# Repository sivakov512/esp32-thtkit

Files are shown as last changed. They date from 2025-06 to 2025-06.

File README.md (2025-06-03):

# ESP32 THT Development Kits
**Ultra-Compact Through-Hole Development Boards for ESP32**



This repository contains design files and documentation for ultra-compact, through-hole (THT) friendly development boards based on Espressif ESP32 microcontrollers. These boards are designed for easy integration into breadboard and other through-hole prototyping environments.

## Available Development Kits

| DevKit | Description | SoC | Features |
|---|---|-----|---|
| [ESP32-C3-THTKIT](esp32-c3-thtkit/) | Ultra-compact ESP32-C3 development board with THT headers | ESP32-C3FH4 | WiFi, Bluetooth 5 (LE), RISC-V single-core |
| [ESP32-H2-THTKIT](esp32-h2-thtkit/) | Ultra-compact ESP32-H2 development board with THT headers | ESP32-H2FH4 | 802.15.4 (Thread, Zigbee), Bluetooth 5 (LE), RISC-V single-core |

## Key Features

- **Ultra-compact form factor**: Minimal dimensions for tight integration
- **Breadboard friendly**: Design optimized for breadboard prototyping
- **THT headers**: Standard 2.54mm pitch through-hole pins
- **Smart header layout**: Bottom header deliberately offset by 1.27mm (half pitch) to prevent accidental shorts in breadboards
- **Simple power supply**: 3.3V to 12V input with onboard LDO
- **Essential pins exposed**: Focused on providing the most important functionality
- **UART debug access**: Dedicated UART pins for easy programming and debugging
- **KiCad design files**: Complete open-source hardware design

## Design Philosophy

These development kits are designed with several principles in mind:
- **Minimal but complete**: Only essential components while maintaining full functionality
- **Direct integration**: Design that works in final projects, not just for prototyping
- **Hackable**: Easy to modify and adapt to specific needs
- **Open design**: Full schematics and PCB files available

## Getting Started

Visit each development kit's directory for specific documentation:

- [ESP32-C3-THTKIT Documentation](esp32-c3-thtkit/)
- [ESP32-H2-THTKIT Documentation](esp32-h2-thtkit/)

## License

This project is released under the [MIT License](LICENSE).

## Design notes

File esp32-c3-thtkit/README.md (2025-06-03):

# ESP32-C3-THTKIT
**Ultra-Compact THT-Friendly DevKit**



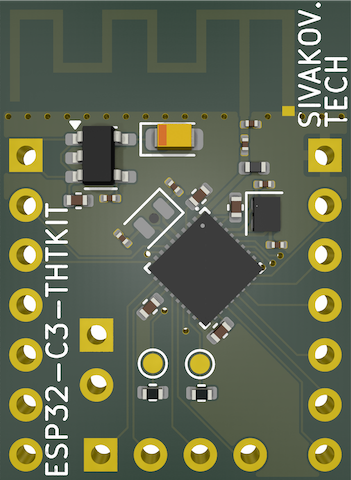
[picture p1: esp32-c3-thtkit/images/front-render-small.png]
Front render


---

## Overview

ESP32-C3-THTKIT is an ultra-compact development board based on the ESP32-C3FH4 SoC. Designed for direct THT integration, it exposes only essential functionality in a minimal form factor. UART pins are easily accessible at the top for in-circuit development.

---

## Pinout

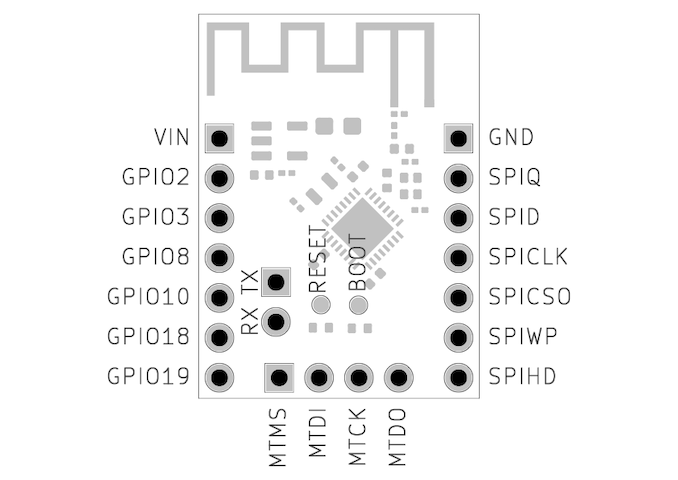
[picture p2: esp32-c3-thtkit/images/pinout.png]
Pinout


- Left header (THT): VIN, GPIO2 to GPIO19
- Right header (THT): GND, GPIO17 to GPIO12 (FSPI2 by default)
- Bottom header (THT): GPIO4 to GPIO7 (JTAG by default)
- Top edge: UART TX/RX pins
- BOOT/RESET: pad-based activation (short to GND)
- Pin pitch: 2.54 mm standard
- Bottom header deliberately offset by 1.27 mm (half pitch) to prevent accidental shorts when inserted into a breadboard

---

## Programming & Debugging

- UART programming recommended via top pins
- JTAG available on bottom header (default mapping)
- No USB functionality

---

## Electrical

- Input Voltage: 3.3V to 12V
- On-board LDO stabilizes to 3.3V
- No onboard USB

---

## Mechanical

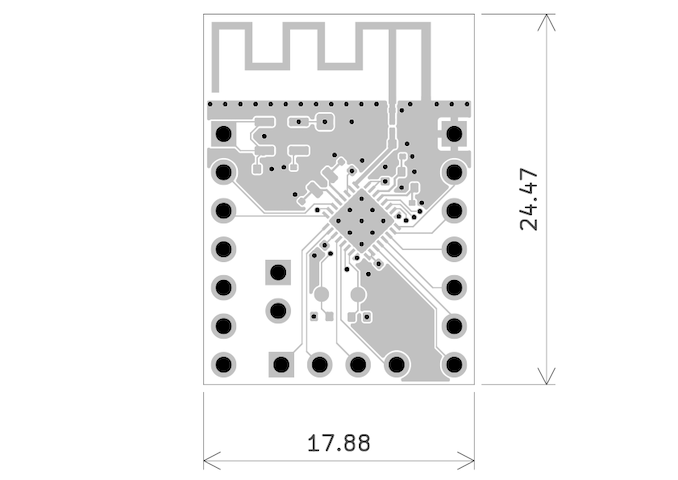
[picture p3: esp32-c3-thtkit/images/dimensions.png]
Dimensions


- Dimensions: 24.47 mm x 17.88 mm
- 3x THT headers: left, right, and optional bottom (user-soldered)

---

## Datasheet

[📄 ESP32-H2-THTKIT Datasheet (PDF)](docs/Datasheet.pdf)

[📄 ESP32-H2 Datasheet (Espressif)](https://cdn.jsdelivr.net/gh/sivakov512/kicad-library@master/datasheets/MCU/Espressif/Espressif_ESP32-H2.pdf)

---

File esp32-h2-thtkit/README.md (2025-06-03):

# ESP32-H2-THTKIT
**Ultra-Compact THT-Friendly DevKit**



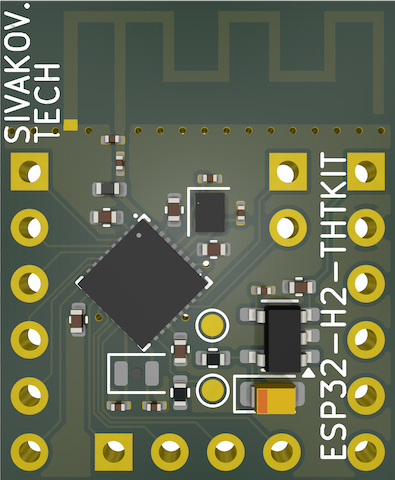
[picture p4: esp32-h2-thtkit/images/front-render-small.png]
Front render


---

## Overview

ESP32-H2-THTKIT is an ultra-compact development board based on the ESP32-H2FH4 SoC. Designed for direct integration into through-hole (THT) projects, it contains only the essential components and remains breadboard-friendly. UART debug pins are routed to the top for easy access during development, regardless of installation density.

---

## Pinout

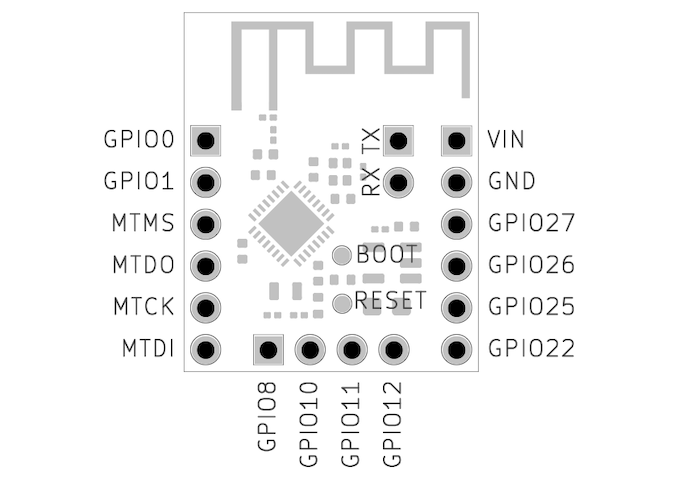
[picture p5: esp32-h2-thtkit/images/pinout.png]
Pinout


- Left header (THT): GPIO0 to GPIO5 (also FSPI2-capable)
- Right header (THT): VIN, GND, GPIO27 to GPIO22
- Bottom header (THT): GPIO8, GPIO10, GPIO11, GPIO12 (can be used as JTAG)
- Top edge: UART TX/RX pins
- BOOT/RESET: pad-based activation (short to GND)
- Pin pitch: 2.54 mm standard
- Bottom header deliberately offset by 1.27 mm (half pitch) to prevent accidental shorts when inserted into a breadboard

---

## Programming & Debugging

- UART programming recommended via top pins
- JTAG support via GPIO8/10/11/12 (if remapped)
- No USB functionality

---

## Electrical

- Input Voltage: 3.3V to 12V
- On-board LDO stabilizes to 3.3V
- No onboard USB

---

## Mechanical

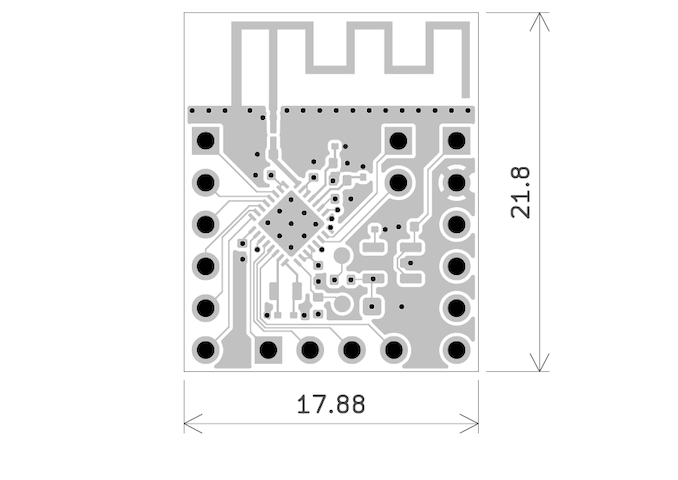
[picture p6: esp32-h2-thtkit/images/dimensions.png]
Dimensions


- Dimensions: 21.8 mm x 17.88 mm
- 3x THT headers: left, right, and optional bottom (user-soldered)

---

## Datasheet

[📄 ESP32-C3-THTKIT Datasheet (PDF)](docs/Datasheet.pdf)

[📄 ESP32-C3 Datasheet (Espressif)](https://cdn.jsdelivr.net/gh/sivakov512/kicad-library@master/datasheets/MCU/Espressif/Espressif_ESP32-C3.pdf)

---

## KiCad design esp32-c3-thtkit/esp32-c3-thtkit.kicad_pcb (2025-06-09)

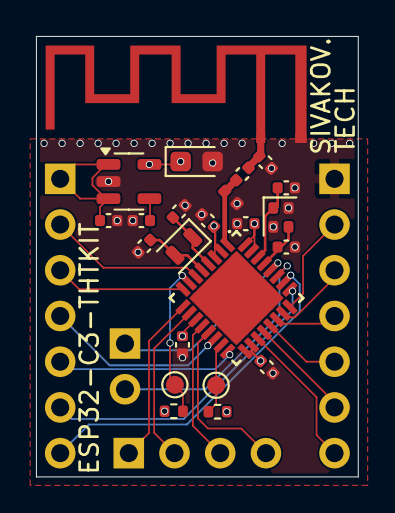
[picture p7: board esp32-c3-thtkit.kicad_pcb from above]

Board: 4 copper layers, 17.9 x 24.5 mm, 27 parts (0 on the bottom side), 30 nets.

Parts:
AE1: Antenna_Chip; Antenna_PCB_Espressif_2.4GHz_Left
C1: 1m 6.3V X7R; C_0402_1005Metric
C2: 470p 6.3V X7R; C_0402_1005Metric
C3: 2.2m 6.3V TANT; CP_EIA-2012-12_Kemet-R
C4, C5, C6, C8: 100n 6.3V X7R; C_0402_1005Metric
C7: 5.6p C0G; C_0402_1005Metric
C9: 2.2p C0G; C_0402_1005Metric
C10, C13: 15p 6.3V C0G; C_0402_1005Metric
C11, C12: 25p 6.3V C0G; C_0402_1005Metric
J1: PIN_GROUP_1; PinHeader_1x07_P2.54mm_Vertical_NoSilk
J2: PIN_GROUP_3; PinHeader_1x07_P2.54mm_Vertical_NoSilk
J3: PIN_GROUP_2; PinHeader_1x04_P2.54mm_Vertical_NoSilk
J4: UART; PinHeader_1x02_P2.54mm_Vertical_NoSilk
L1: 3.9 nH; L_0402_1005Metric
R1, R2: 10k; R_0402_1005Metric
TP1, TP2: TestPoint; TestPoint_Pad_D1.0mm
U1: MIC5219-3.3YM5; SOT-23-5
U2: ESP32-C3; VFQFN_32_1EP_5x5mm_P0.5mm_EP3.2x3.2mm_Compact
Y1: 32.768kHz ±20ppm CL12.5pF; Crystal_SMD_2012-2Pin_2.0x1.2mm
Y2: 40MHz ±10ppm CL8pF; Crystal_SMD_1612-4Pin_1.6x1.2mm

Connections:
+3.3V: C3.1, C4.2, C5.2, C6.2, C8.2, R1.2, R2.2, U1.5 (OUT), U2.2 (VDD3P3), U2.3 (VDD3P3), U2.11 (VDD3P3_RTC), U2.17 (VDD3P3_CPU), U2.18 (VDD_SPI), U2.31 (VDDA), U2.32 (VDDA)
/BOOT: R1.1, TP1.1, U2.15 (GPIO9)
/GPIO2: J2.2, U2.6 (GPIO2)
/GPIO3: J2.3, U2.8 (GPIO3)
/GPIO8: J2.4, U2.14 (GPIO8)
/GPIO10: J2.5, U2.16 (GPIO10)
/GPIO18: J2.6, U2.25 (GPIO18)
/GPIO19: J2.7, U2.26 (GPIO19)
/MTCK: J3.3, U2.12 (MTCK)
/MTDI: J3.2, U2.10 (MTDI)
/MTDO: J3.4, U2.13 (MTDO)
/MTMS: J3.1, U2.9 (MTMS)
/RESET: R2.1, TP2.1, U2.7 (CHIP_EN)
/RF: C7.2, L1.1, U2.1 (LNA_IN)
/SPICLK: J1.4, U2.22 (SPICLK)
/SPICS0: J1.5, U2.21 (SPICS0)
/SPID: J1.3, U2.23 (SPID)
/SPIHD: J1.7, U2.19 (SPIHD)
/SPIQ: J1.2, U2.24 (SPIQ)
/SPIWP: J1.6, U2.20 (SPIWP)
/U0RXD: J4.2, U2.27 (U0RXD)
/U0TXD: J4.1, U2.28 (U0TXD)
/XTAL_32K_N: C12.2, U2.5 (XTAL_32K_N), Y1.2
/XTAL_32K_P: C11.2, U2.4 (XTAL_32K_P), Y1.1
/XTAL_N: C13.2, U2.29 (XTAL_N), Y2.3
/XTAL_P: C10.1, U2.30 (XTAL_P), Y2.1
GND: AE1.2 (PCB_Trace), C1.1, C2.1, C3.2, C4.1, C5.1, C6.1, C8.1, C9.1, C10.2, C11.1, C12.1, C13.1, J1.1, L1.2, U1.2 (GND), U2.33 (GND), Y2.2, Y2.4
unnamed: AE1.1 (FEED), C7.1, C9.2
unnamed: C2.2, U1.4 (BP)
VIN: C1.2, J2.1, U1.1 (IN), U1.3 (EN)

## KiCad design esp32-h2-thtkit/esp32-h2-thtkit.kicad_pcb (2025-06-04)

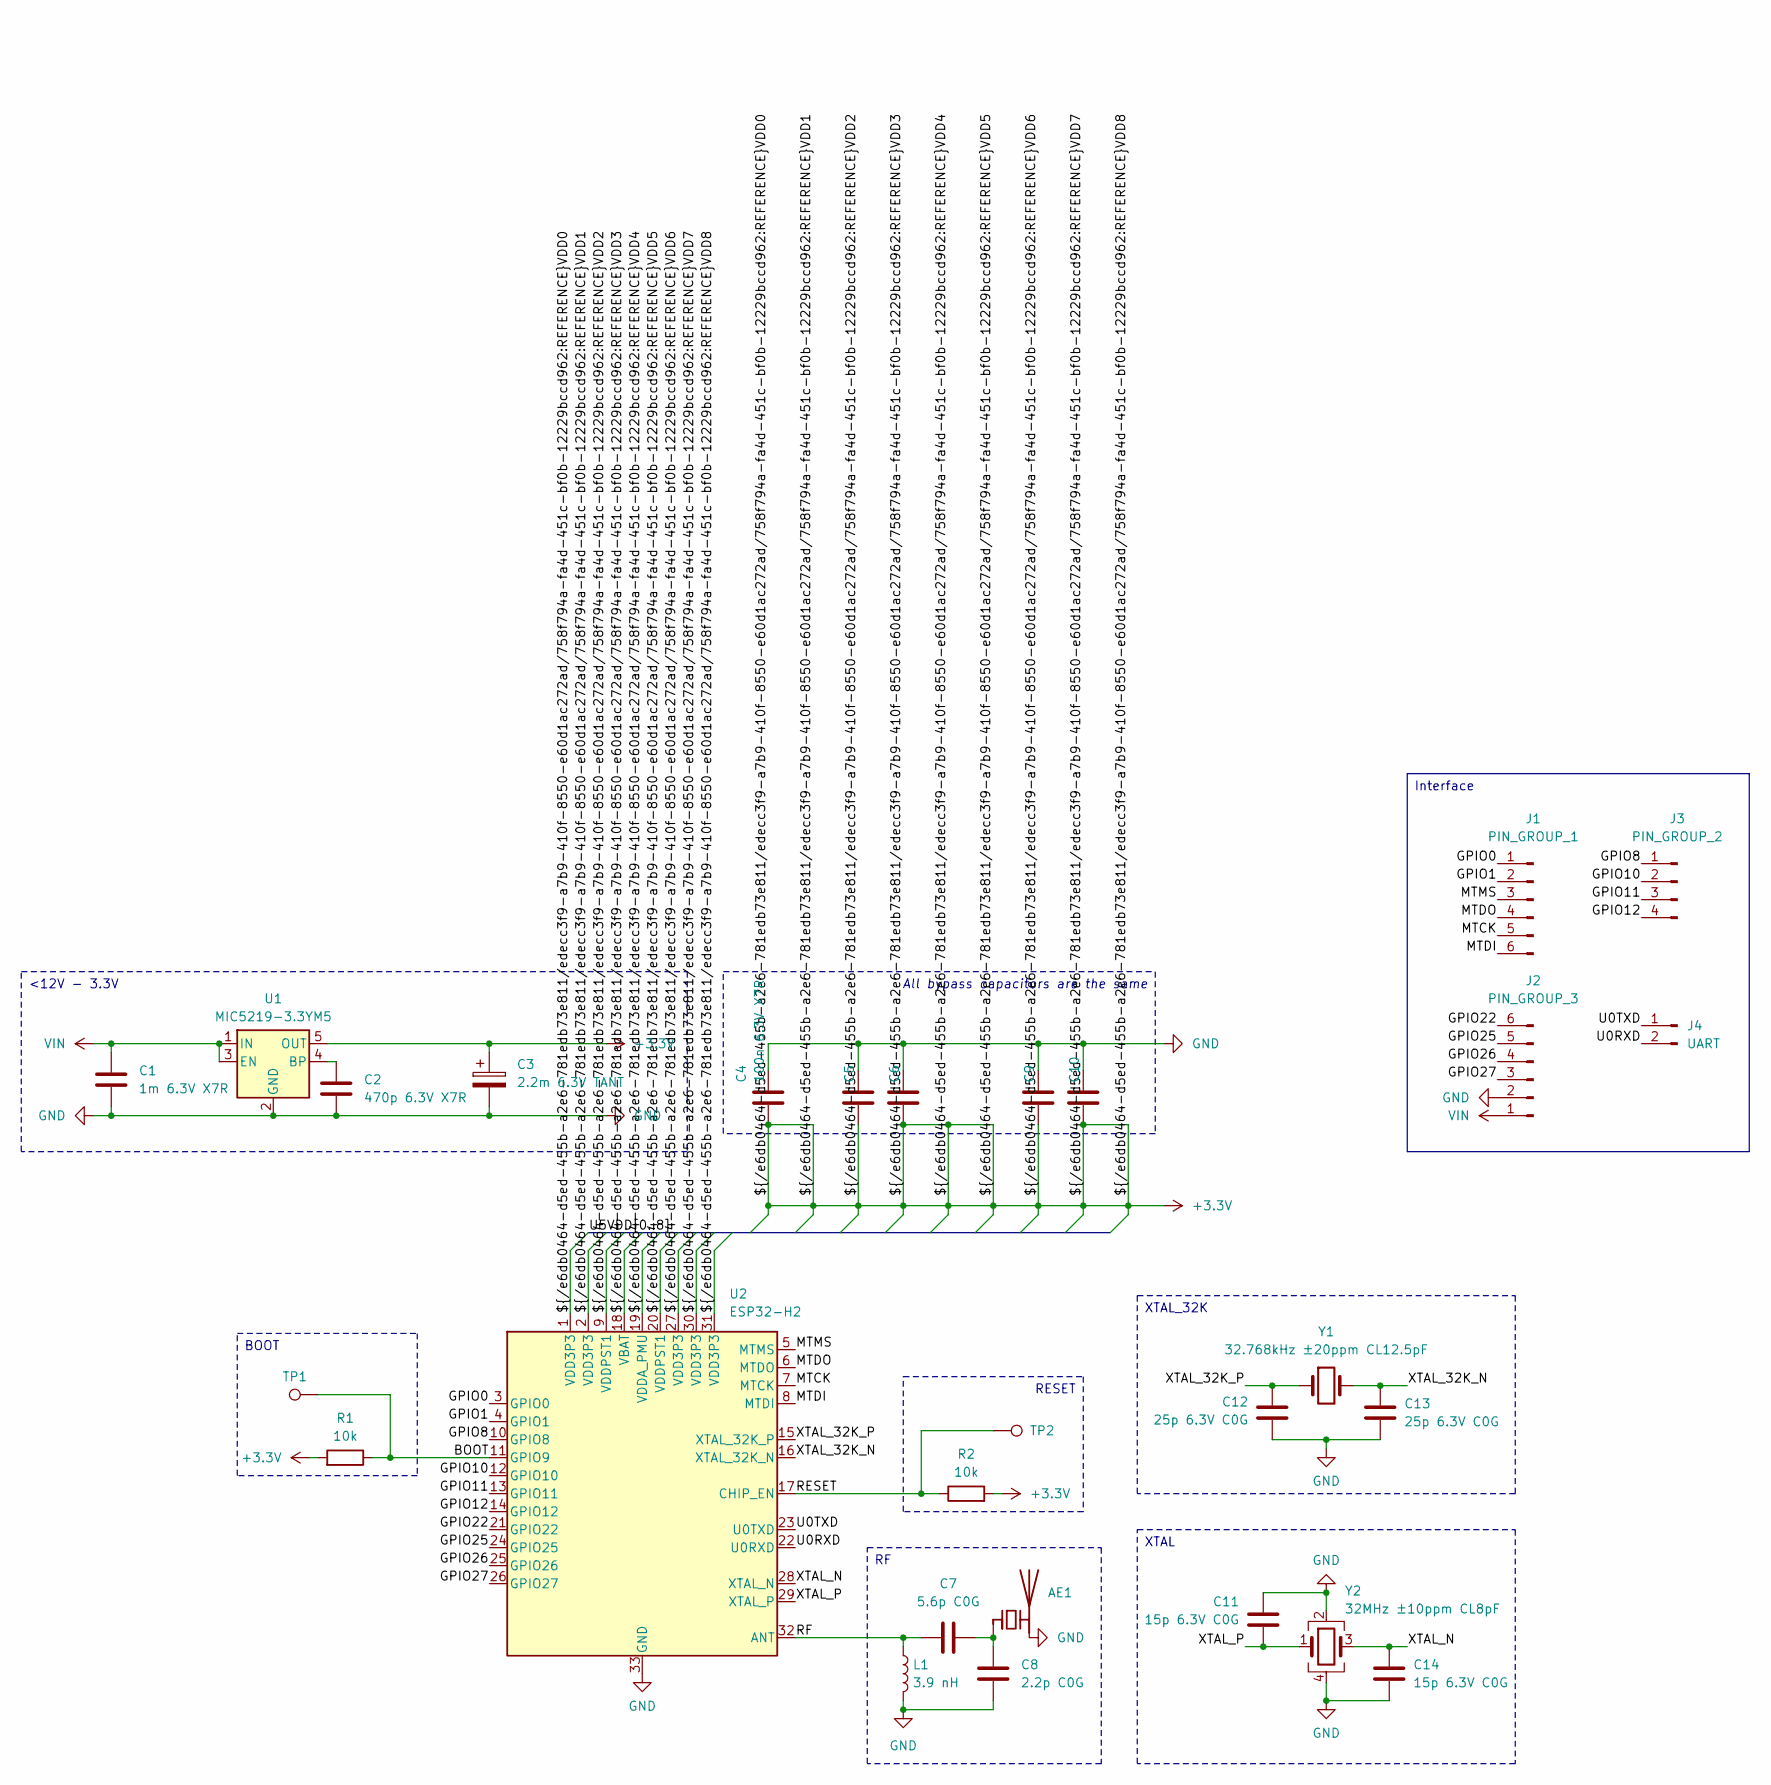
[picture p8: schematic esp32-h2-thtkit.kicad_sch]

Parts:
AE1: Antenna_Chip; Antenna_PCB_Espressif_2.4GHz_Right
C1: 1m 6.3V X7R; C_0402_1005Metric; LCSC PN C307427
C2: 470p 6.3V X7R; C_0402_1005Metric; LCSC PN C1537
C3: 2.2m 6.3V TANT; CP_EIA-2012-12_Kemet-R; LCSC PN C444770
C4, C5, C6, C9, C10: 100n 6.3V X7R; C_0402_1005Metric; LCSC PN C309458
C7: 5.6p C0G; C_0402_1005Metric; LCSC PN C1574
C8: 2.2p C0G; C_0402_1005Metric; LCSC PN C1559
C11, C14: 15p 6.3V C0G; C_0402_1005Metric; LCSC PN C1548
C12, C13: 25p 6.3V C0G; C_0402_1005Metric; LCSC PN C1556
J1: PIN_GROUP_1; PinHeader_1x06_P2.54mm_Vertical_NoSilk
J2: PIN_GROUP_3; PinHeader_1x06_P2.54mm_Vertical_NoSilk
J3: PIN_GROUP_2; PinHeader_1x04_P2.54mm_Vertical_NoSilk
J4: UART; PinHeader_1x02_P2.54mm_Vertical_NoSilk; LCSC PN C7501580
L1: 3.9 nH; L_0402_1005Metric; LCSC PN C77109
R1, R2: 10k; R_0402_1005Metric; LCSC PN C25744
TP1, TP2: TestPoint; TestPoint_Pad_D1.0mm
U1: MIC5219-3.3YM5; SOT-23-5; LCSC PN C29613
U2: ESP32-H2; TQFN_32_1EP_4x4mm_P0.4mm_EP2.4x2.4mm_Compact; LCSC PN C22470214
Y1: 32.768kHz ±20ppm CL12.5pF; Crystal_SMD_2012-2Pin_2.0x1.2mm; LCSC PN C55208
Y2: 32MHz ±10ppm CL8pF; Crystal_SMD_1612-4Pin_1.6x1.2mm; LCSC PN C7301921

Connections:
+3.3V: C3.1, C4.2, C5.2, C6.2, C9.2, C10.2, R1.2, R2.2, U1.5 (OUT), U2.1 (VDD3P3), U2.2 (VDD3P3), U2.9 (VDDPST1), U2.18 (VBAT), U2.19 (VDDA_PMU), U2.20 (VDDPST1), U2.27 (VDD3P3), U2.30 (VDD3P3), U2.31 (VDD3P3)
/BOOT: R1.1, TP1.1, U2.11 (GPIO9)
/GPIO0: J1.1, U2.3 (GPIO0)
/GPIO1: J1.2, U2.4 (GPIO1)
/GPIO8: J3.1, U2.10 (GPIO8)
/GPIO10: J3.2, U2.12 (GPIO10)
/GPIO11: J3.3, U2.13 (GPIO11)
/GPIO12: J3.4, U2.14 (GPIO12)
/GPIO22: J2.6, U2.21 (GPIO22)
/GPIO25: J2.5, U2.24 (GPIO25)
/GPIO26: J2.4, U2.25 (GPIO26)
/GPIO27: J2.3, U2.26 (GPIO27)
/MTCK: J1.5, U2.7 (MTCK)
/MTDI: J1.6, U2.8 (MTDI)
/MTDO: J1.4, U2.6 (MTDO)
/MTMS: J1.3, U2.5 (MTMS)
/RESET: R2.1, TP2.1, U2.17 (CHIP_EN)
/RF: C7.2, L1.1, U2.32 (ANT)
/U0RXD: J4.2, U2.22 (U0RXD)
/U0TXD: J4.1, U2.23 (U0TXD)
/XTAL_32K_N: C13.2, U2.16 (XTAL_32K_N), Y1.2
/XTAL_32K_P: C12.2, U2.15 (XTAL_32K_P), Y1.1
/XTAL_N: C14.2, U2.28 (XTAL_N), Y2.3
/XTAL_P: C11.1, U2.29 (XTAL_P), Y2.1
GND: AE1.2 (PCB_Trace), C1.1, C2.1, C3.2, C4.1, C5.1, C6.1, C8.1, C9.1, C10.1, C11.2, C12.1, C13.1, C14.1, J2.2, L1.2, U1.2 (GND), U2.33 (GND), Y2.2, Y2.4
unnamed: AE1.1 (FEED), C7.1, C8.2
unnamed: C2.2, U1.4 (BP)
VIN: C1.2, J2.1, U1.1 (IN), U1.3 (EN)

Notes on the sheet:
XTAL
RESET
XTAL_32K
All bypass capacitors are the same
BOOT
Interface
<12V - 3.3V

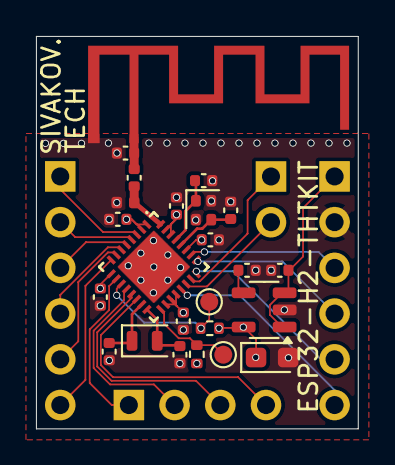
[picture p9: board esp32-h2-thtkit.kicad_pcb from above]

Board: 4 copper layers, 17.9 x 21.8 mm, 28 parts (0 on the bottom side), 28 nets.

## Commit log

2025-05-28 Ignore KiCad specific stuff
2025-05-28 Define esp32-h2 schematic
    [esp32-h2-thtkit.kicad_pcb, esp32-h2-thtkit.kicad_sch]
2025-05-28 Use connectors without silkscreen to place them right on the corner
    [esp32-h2-thtkit.kicad_sch]
2025-05-28 Basic components layout
    [esp32-h2-thtkit.kicad_pcb]
2025-05-29 Full schematic and PCB layout for esp32-h2 tht kit
    [esp32-h2-thtkit.kicad_pcb, esp32-h2-thtkit.kicad_sch]
2025-05-29 Added 32k crystal, updated footprint, few rearranges
    [esp32-h2-thtkit.kicad_sch]
2025-06-01 Improve layout to make better SPI routes
    [esp32-h2-thtkit.kicad_pcb, esp32-h2-thtkit.kicad_sch]
2025-06-02 Fix antenna layout a bit
    [esp32-h2-thtkit.kicad_pcb]
2025-06-02 The same devkit for C3
    [esp32-c3-thtkit.kicad_pcb, esp32-c3-thtkit.kicad_sch]
2025-06-02 Change some manufacturing related attributes
    [esp32-c3-thtkit.kicad_pcb, esp32-c3-thtkit.kicad_sch, esp32-h2-thtkit.kicad_pcb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]
2025-06-02 Draw pin layout on user layer
    [esp32-c3-thtkit.kicad_pcb, esp32-h2-thtkit.kicad_pcb]
2025-06-02 esp32-c3-thtkit documentation
2025-06-02 esp32-h2-thtkit documenation
2025-06-03 Add ESP32 THT development kits documentation
2025-06-04 Make devkits cheaper by using 0402 components instead of 0201
    [esp32-c3-thtkit.kicad_pcb, esp32-c3-thtkit.kicad_sch, esp32-h2-thtkit.kicad_pcb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]
2025-06-05 Change microcontroller package from 4x4 to 5x5
    [esp32-c3-thtkit.kicad_pcb, esp32-c3-thtkit.kicad_sch]
2025-06-09 Unify schemas and fix esp32-c3 footprint
    [esp32-c3-thtkit.kicad_pcb, esp32-c3-thtkit.kicad_sch, esp32-h2-thtkit.kicad_sch]
